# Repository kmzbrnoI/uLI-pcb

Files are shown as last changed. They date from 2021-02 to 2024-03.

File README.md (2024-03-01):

uLI – Ultimate LI PCB
=====================

uLI is a XpressNET &#8596; USB converter behaving as COM port in PC (CDC).

## uLI v5

* Designed in: KiCad 7
* Main Processor: PIC18F14K50
* Several enhancements from uLI v4, backward-compatible.
  - See releases/tags for a list of modifications from uLI v4.
* Firmware is same for v4 & v5.
* Authors: Jan Horacek (c) 2024

## uLI v4

* Deprecated.
* Designed in: Eagle 9
* Main Processor: PIC18F14K50
* Authors: Jan Horacek, Michal Petrilak (c) 2016

## Firmware

* [uLI-fw](https://github.com/kmzbrnoI/uLI-fw)
* [uLI-master-fw](https://github.com/kmzbrnoI/uLI-master-fw)

## Further reading

- [About XpressNET](http://www.opendcc.de/info/xpressnet/xpressnet_e.html)
- uLI meets [XpressNET specification v3](http://www.lenzusa.com/1newsite1/Manuals/xpressnet.pdf)
- uLI should also meet [XpressNET specification v3.6](http://wiki.rocrail.net/lib/exe/fetch.php?id=xpressnet-en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) (available only in German)

## License

Content of the repository is provided under [Creative Commons
Attribution-ShareAlike 4.0
License](https://creativecommons.org/licenses/by-sa/4.0/) as openhardware
project. You may download any data, contribute to the project, create PCB
yourself or even sell it yourself.

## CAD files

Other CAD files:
cnc/uLI-04-top.dwg
cnc/uLI-04-bottom.dwg

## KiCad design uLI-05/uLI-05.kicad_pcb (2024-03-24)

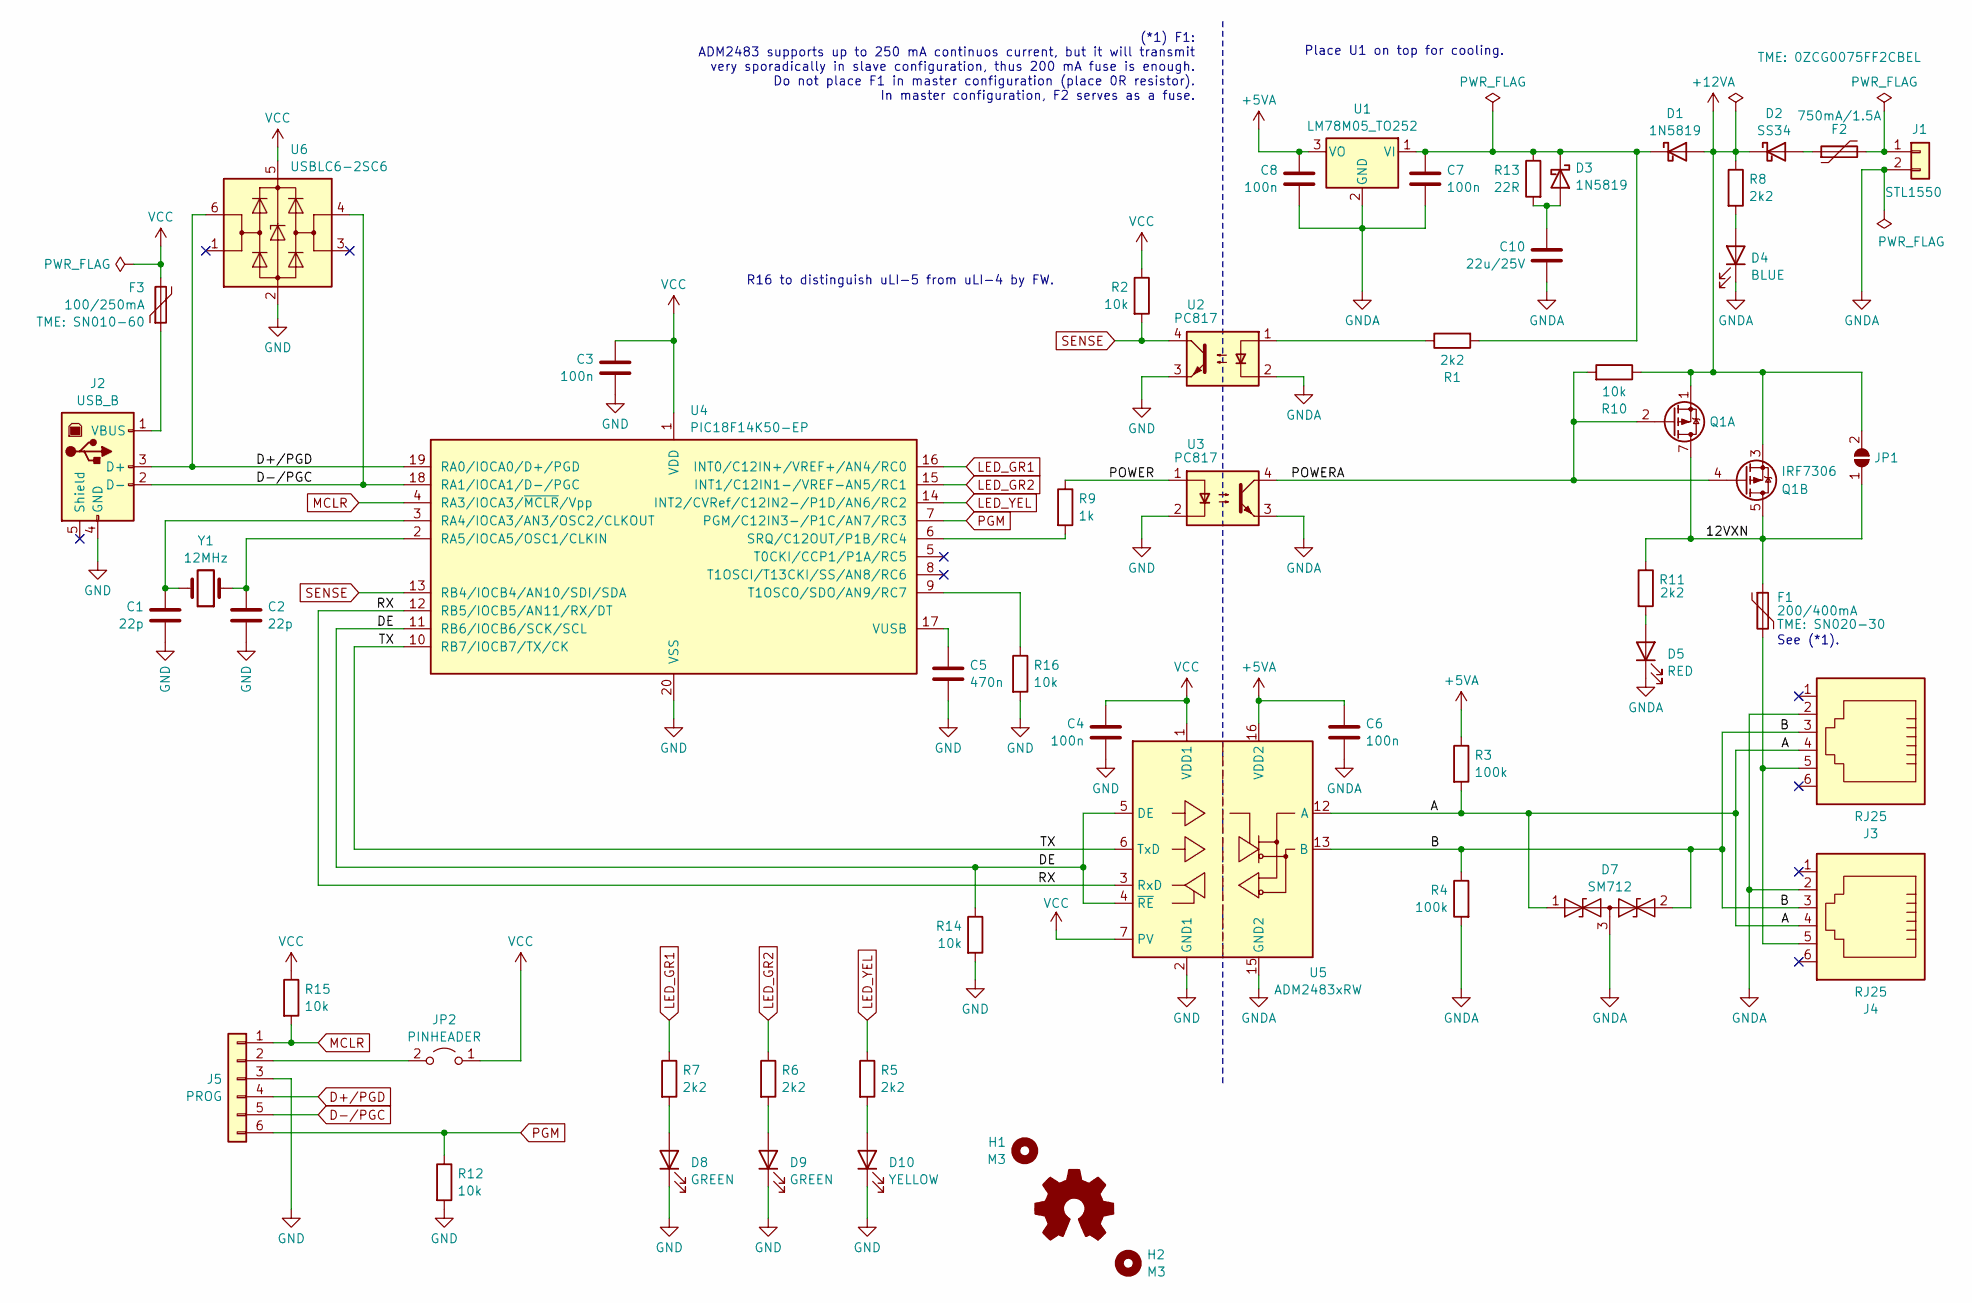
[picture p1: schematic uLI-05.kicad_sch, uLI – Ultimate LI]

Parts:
C1, C2: 22p; C_0805_2012Metric; LCSC C1804
C3, C4, C6, C7, C8: 100n; C_0805_2012Metric; LCSC C49678
C5: 470n; C_0805_2012Metric; LCSC C13967
C10: 22u/25V; C_0805_2012Metric; LCSC C45783
D1, D3: 1N5819; D_SOD-123; LCSC C8598
D2: SS34; D_SMA; LCSC C8678
D4: BLUE; LED_D3.0mm; JLCPCB_IGNORE true
D5: RED; LED_D3.0mm; JLCPCB_IGNORE true
D7: SM712; SOT-23; LCSC C32677
D8, D9: GREEN; LED_D3.0mm; JLCPCB_IGNORE true
D10: YELLOW; LED_D3.0mm; JLCPCB_IGNORE true
F1: 200/400mA; Fuse_1206_3216Metric; JLCPCB_IGNORE true
F2: 750mA/1.5A; Fuse_1812_4532Metric; JLCPCB_IGNORE true
F3: 100/250mA; Fuse_1206_3216Metric; JLCPCB_IGNORE true
H1, H2: M3; MountingHole_3.2mm_M3_Pad; JLCPCB_IGNORE true
J1: STL1550; PhoenixContact_MC_1,5_2-G-3.5_1x02_P3.50mm_Horizontal; JLCPCB_IGNORE true
J2: USB_B; USB_B_OST_USB-B1HSxx_Horizontal; JLCPCB_IGNORE true
J3, J4: RJ25; RJ12_Amphenol_54601-x06_Horizontal; JLCPCB_IGNORE true
J5: PROG; PinHeader_1x06_P2.54mm_Vertical; JLCPCB_IGNORE true
JP1: SolderJumper-2_P1.3mm_Open_RoundedPad1.0x1.5mm; JLCPCB_IGNORE true
JP2: PINHEADER; PinHeader_1x02_P2.54mm_Vertical; JLCPCB_IGNORE true
Q1: IRF7306; SOIC-8_3.9x4.9mm_P1.27mm; LCSC C879047
R1, R5, R6, R7, R8, R11: 2k2; R_0805_2012Metric; LCSC C17520
R2, R10, R12, R14, R15, R16: 10k; R_0805_2012Metric; LCSC C17414
R3, R4: 100k; R_0805_2012Metric; LCSC C149504
R9: 1k; R_0805_2012Metric; LCSC C17513
R13: 22R; R_0805_2012Metric; LCSC C17561
U1: LM78M05_TO252; TO-252-2; JLCPCB_IGNORE true
U2, U3: PC817; DIP-4_W7.62mm; JLCPCB_IGNORE true
U4: PIC18F14K50-EP; SSOP-20_5.3x7.2mm_P0.65mm; LCSC C12460
U5: ADM2483xRW; SOIC-16W_7.5x10.3mm_P1.27mm; LCSC C386280
U6: USBLC6-2SC6; SOT-23-6; JLCPCB_IGNORE true
Y1: 12MHz; Crystal_HC49-4H_Vertical; JLCPCB_IGNORE true

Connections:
+5VA: C6.1, C8.1, R3.1, U1.3 (VO), U5.16 (VDD2)
+12VA: D1.2 (A), D2.1 (K), JP1.2 (B), Q1.1 (S1), Q1.3 (S2), R8.1, R10.1
/12VXN: F1.1, JP1.1 (A), Q1.5 (D2), Q1.6 (D2), Q1.7 (D1), Q1.8 (D1), R11.1
/A: D7.1 (A1), J3.4, J4.4, R3.2, U5.12 (A)
/B: D7.2 (A2), J3.3, J4.3, R4.1, U5.13 (B)
/DE: R14.1, U4.11 (RB6/IOCB6/SCK/SCL), U5.4 (~RE), U5.5 (DE)
/POWER: R9.1, U3.1
/POWERA: Q1.2 (G1), Q1.4 (G2), R10.2, U3.4
/RX: U4.12 (RB5/IOCB5/AN11/RX/DT), U5.3 (RxD)
/TX: U4.10 (RB7/IOCB7/TX/CK), U5.6 (TxD)
D+/PGD: J2.3 (D+), J5.4, U4.19 (RA0/IOCA0/D+/PGD), U6.6 (I/O1)
D-/PGC: J2.2 (D-), J5.5, U4.18 (RA1/IOCA1/D-/PGC), U6.4 (I/O2)
GND: C1.1, C2.1, C3.2, C4.2, C5.2, D8.1 (K), D9.1 (K), D10.1 (K), J2.4 (GND), J5.3, R12.2, R14.2, R16.2, U2.3, U3.2, U4.20 (VSS), U5.2 (GND1), U5.8 (GND1), U6.2 (GND)
GNDA: C6.2, C7.2, C8.2, C10.2, D4.1 (K), D5.1 (K), D7.3 (common), J1.2, J3.2, J4.2, R4.2, U1.2 (GND), U2.2, U3.3, U5.9 (GND2), U5.15 (GND2)
LED_GR1: R7.1, U4.16 (INT0/C12IN+/VREF+/AN4/RC0)
LED_GR2: R6.1, U4.15 (INT1/C12IN1-/VREF-AN5/RC1)
LED_YEL: R5.1, U4.14 (INT2/CVRef/C12IN2-/P1D/AN6/RC2)
MCLR: J5.1, R15.2, U4.4 (RA3/IOCA3/~MCLR/Vpp)
unnamed: C7.1, D1.1 (K), D3.1 (K), R1.2, R13.1, U1.1 (VI)
unnamed: D2.2 (A), F2.1
unnamed: C10.1, D3.2 (A), R13.2
unnamed: D4.2 (A), R8.2
unnamed: D5.2 (A), R11.2
unnamed: D8.2 (A), R7.2
unnamed: D9.2 (A), R6.2
unnamed: D10.2 (A), R5.2
unnamed: F1.2, J3.5, J4.5
unnamed: F2.2, J1.1
unnamed: F3.1, J2.1 (VBUS)
unnamed: J5.2, JP2.2 (B)
unnamed: R1.1, U2.1
unnamed: C1.2, U4.3 (RA4/IOCA3/AN3/OSC2/CLKOUT), Y1.2
unnamed: C2.2, U4.2 (RA5/IOCA5/OSC1/CLKIN), Y1.1
unnamed: R9.2, U4.6 (SRQ/C12OUT/P1B/RC4)
unnamed: R16.1, U4.9 (T1OSCO/SDO/AN9/RC7)
unnamed: C5.1, U4.17 (VUSB)
PGM: J5.6, R12.1, U4.7 (PGM/C12IN3-/P1C/AN7/RC3)
SENSE: R2.2, U2.4, U4.13 (RB4/IOCB4/AN10/SDI/SDA)
VCC: C3.1, C4.1, F3.2, JP2.1 (A), R2.1, R15.1, U4.1 (VDD), U5.1 (VDD1), U5.7 (PV), U6.5 (VBUS)

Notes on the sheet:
R16 to distinguish uLI-5 from uLI-4 by FW.
Place U1 on top for cooling.
See (*1).
(*1) F1: ADM2483 supports up to 250 mA continuos current, but it will transmit very sporadically in slave configuration, thus 200 mA fuse is enough. Do not place F1 in master configuration (place 0R resistor). In master configuration, F2 serves as a fuse.

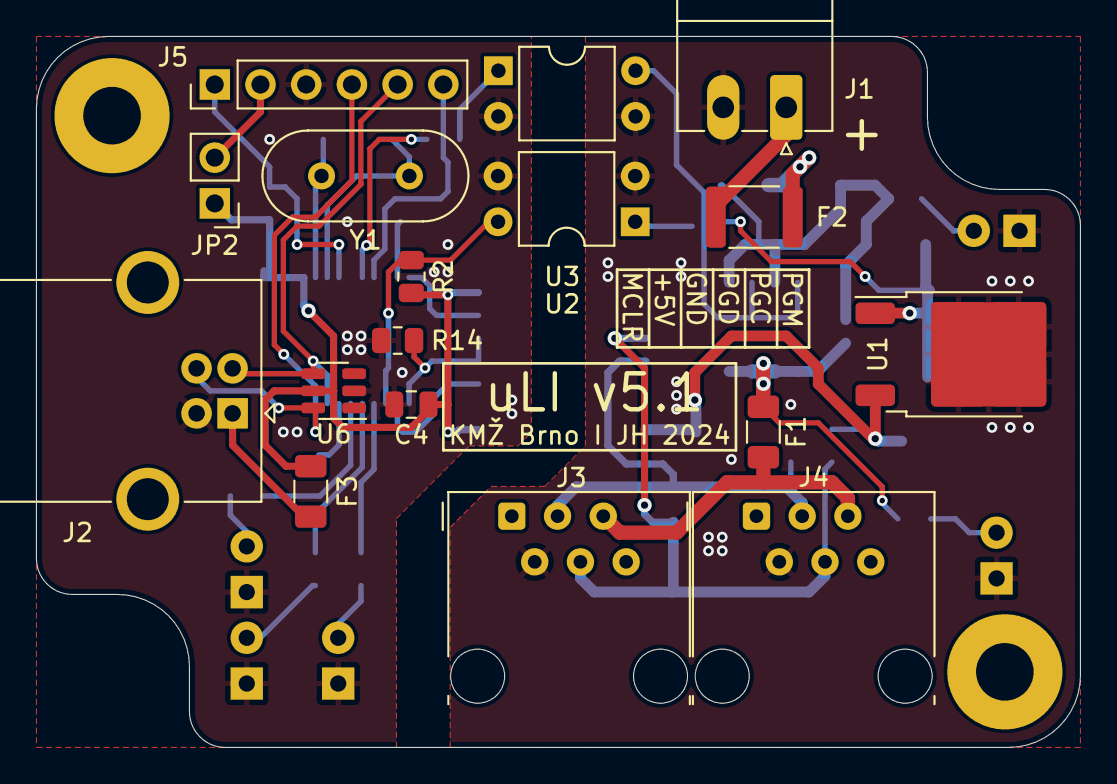
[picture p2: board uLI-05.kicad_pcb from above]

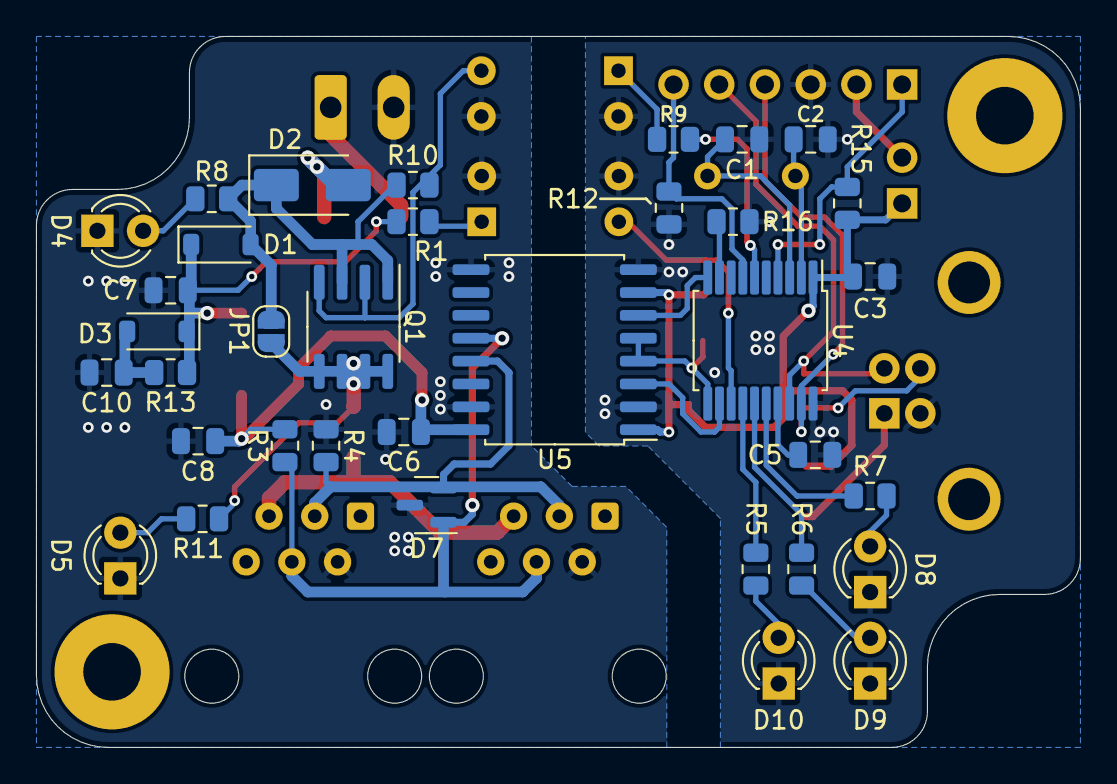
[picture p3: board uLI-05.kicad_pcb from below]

Board: 2 copper layers, 58.0 x 39.5 mm, 54 parts (35 on the bottom side), 39 nets.

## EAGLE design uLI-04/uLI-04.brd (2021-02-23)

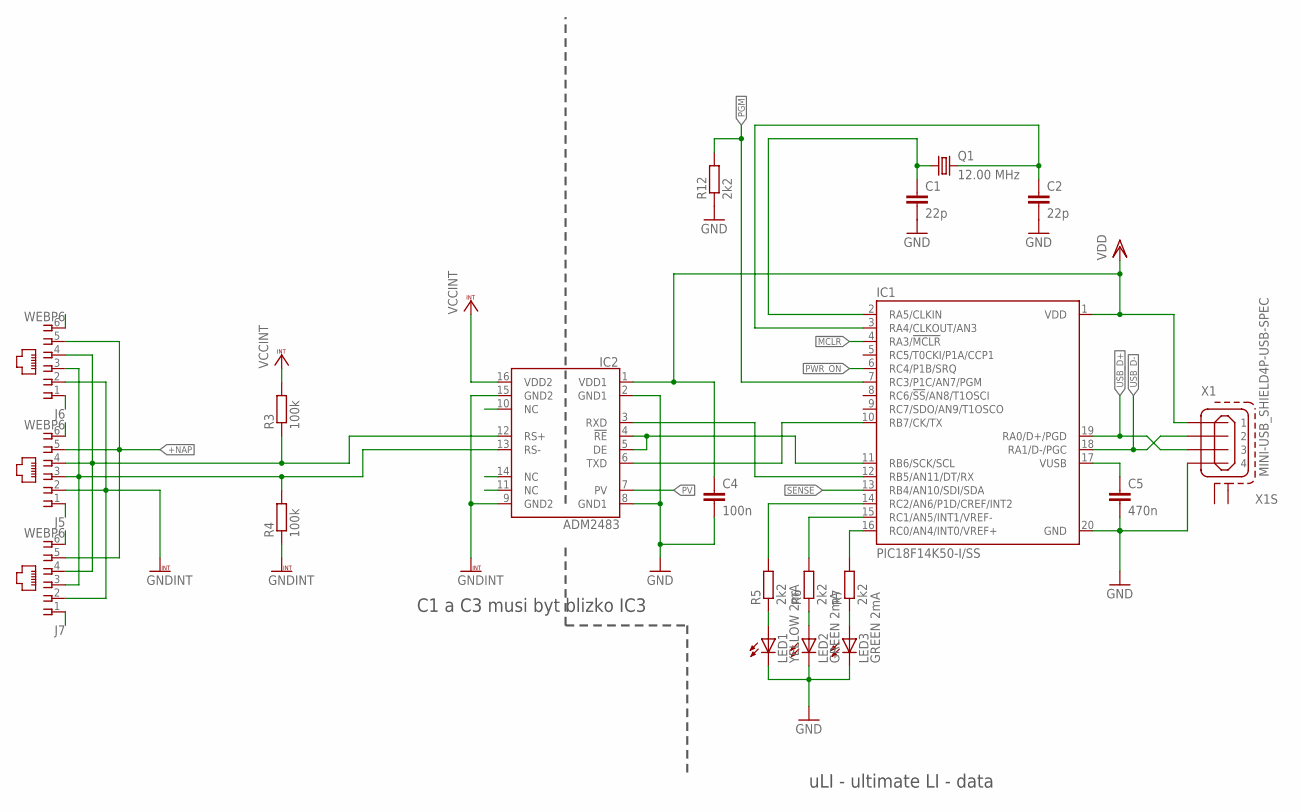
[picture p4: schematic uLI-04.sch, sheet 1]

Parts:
C1, C2: 22p; C0805
C4: 100n; C1206
C5: 470n; C1206
IC1: PIC18F14K50-I/SS; SSOP20
IC2: ADM2483; SO-16W
J5, J6, J7: WEBP6; WEBP6-6_SPEC2
LED1: YELLOW 2mA; LED3MM
LED2, LED3: GREEN 2mA; LED3MM
Q1: 12.00 MHz; HC49U70
R3, R4: 100k; R1206
R5, R6, R7, R12: 2k2; R1206
X1: MINI-USB_SHIELD4P-USB-SPEC; 85-32004-10X-SPEC

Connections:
!MCLR: IC1.4 (RA3/!MCLR!); also elsewhere on the board
+NAP: J5.5, J6.5, J7.5; also elsewhere on the board
BUS_A: IC2.12 (RS+), J5.4, J6.4, J7.4, R3.1
BUS_B: IC2.13 (RS-), J5.3, J6.3, J7.3, R4.2
GND: C1.2, C2.2, C4.2, C5.2, IC1.20 (GND), IC2.2 (GND1), IC2.8 (GND1), LED1.K (C), LED2.K (C), LED3.K (C), R12.1, X1.4; also elsewhere on the board
GNDINT: IC2.9 (GND2), IC2.15 (GND2), J5.2, J6.2, J7.2, R4.1; also elsewhere on the board
LED1: IC1.14 (RC2/AN6/P1D/CREF/INT2), R5.2
LED1_R: LED1.A, R5.1
LED2: IC1.15 (RC1/AN5/INT1/VREF-), R6.2
LED2_R: LED2.A, R6.1
LED3: IC1.16 (RC0/AN4/INT0/VREF+), R7.2
LED3_R: LED3.A, R7.1
unnamed: IC1.12 (RB5/AN11/DT/RX), IC2.3 (RXD)
NC2: IC2.14 (NC)
PGM: IC1.7 (RC3/P1C/AN7/PGM), R12.2; also elsewhere on the board
PROC_RX: IC1.10 (RB7/CK/TX), IC2.6 (TXD)
PROC_TE: IC1.11 (RB6/SCK/SCL), IC2.4 (!RE), IC2.5 (DE)
PV: IC2.7 (PV); also elsewhere on the board
PWR_ON: IC1.6 (RC4/P1B/SRQ); also elsewhere on the board
SENSE: IC1.13 (RB4/AN10/SDI/SDA); also elsewhere on the board
USB_D+: IC1.19 (RA0/D+/PGD), X1.3; also elsewhere on the board
USB_D-: IC1.18 (RA1/D-/PGC), X1.2; also elsewhere on the board
VBUS: C5.1, IC1.17 (VUSB)
VCCINT: IC2.16 (VDD2), R3.2; also elsewhere on the board
VDD: C4.1, IC1.1 (VDD), IC2.1 (VDD1), X1.1; also elsewhere on the board
XTAL1: C1.1, IC1.2 (RA5/CLKIN), Q1.1
XTAL2: C2.1, IC1.3 (RA4/CLKOUT/AN3), Q1.2

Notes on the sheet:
uLI - ultimate LI - data
C1 a C3 musi byt blizko IC3

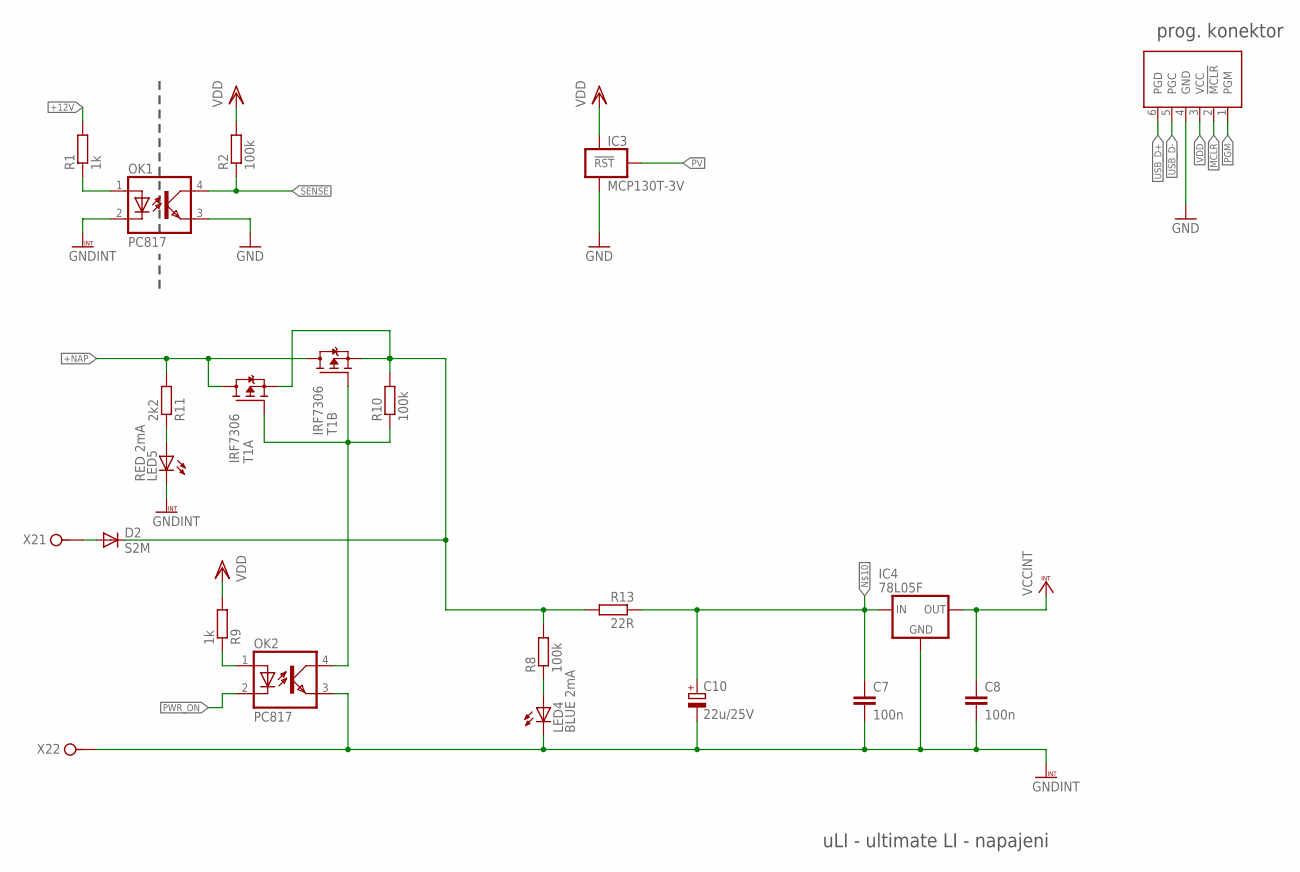
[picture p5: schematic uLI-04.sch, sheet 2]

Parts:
C7, C8: 100n; C1206
C10: 22u/25V; E2-5
D2: S2M; SMB
IC3: MCP130T-3V; SOT23
IC4: 78L05F; SOT89
J1: PICPROG2-V; 6410-06-PICPROG
LED4: BLUE 2mA; LED3MM
LED5: RED 2mA; LED3MM
OK1, OK2: PC817; DIL04
R1, R9: 1k; R1206
R2, R8, R10: 100k; R1206
R11: 2k2; R1206
R13: 22R; R1206
T1: IRF7306; SO08-IRF
X2: ARK1550/2_S; ARK1550/2_SPEC

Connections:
!MCLR: J1.2 (!MCLR); also elsewhere on the board
+12V: D2.C, R1.2, R8.2, R10.2, R13.2, T1.1 (S), T1.3 (S)
+NAP: R11.2, T1.5 (D), T1.6 (D), T1.7 (D), T1.8 (D); also elsewhere on the board
+NAP2: D2.A, X2.1
BUS_SENSE: OK1.1 (A), R1.1
GND: IC3.3 (GND), J1.4 (GND), OK1.3 (EMIT); also elsewhere on the board
GNDINT: C7.2, C8.2, C10.-, IC4.2 (GND), IC4.2@1 (GND), LED4.K (C), LED5.K (C), OK1.2 (C), OK2.3 (EMIT), X2.2; also elsewhere on the board
unnamed: LED4.A, R8.1
unnamed: LED5.A, R11.1
unnamed: OK2.4 (COL), R10.1, T1.2 (G), T1.4 (G)
unnamed: OK2.1 (A), R9.1
unnamed: C7.1, C10.+, IC4.3 (VI), R13.1
PGM: J1.1 (PGM); also elsewhere on the board
PV: IC3.1 (!RST); also elsewhere on the board
PWR_ON: OK2.2 (C); also elsewhere on the board
SENSE: OK1.4 (COL), R2.1; also elsewhere on the board
USB_D+: J1.6 (PGD); also elsewhere on the board
USB_D-: J1.5 (PGC); also elsewhere on the board
VCCINT: C8.1, IC4.1 (VO); also elsewhere on the board
VDD: IC3.2 (VCC), J1.3 (VCC), R2.2, R9.2; also elsewhere on the board

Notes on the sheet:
uLI - ultimate LI - napajeni
prog. konektor

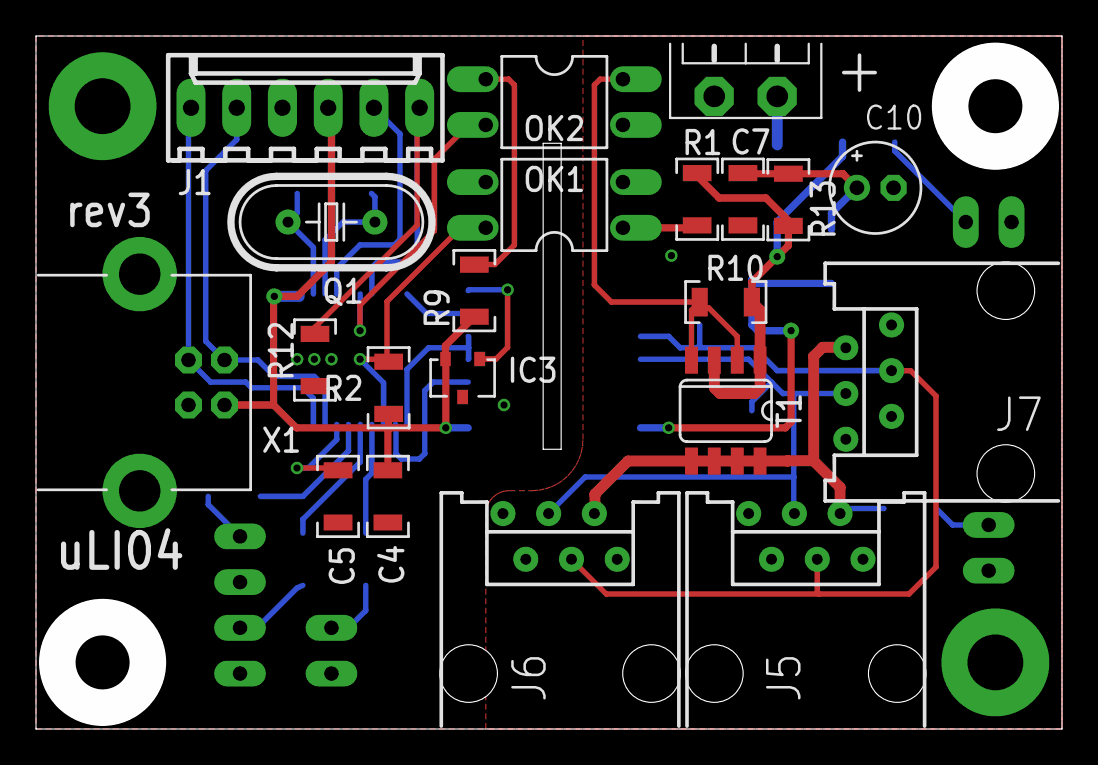
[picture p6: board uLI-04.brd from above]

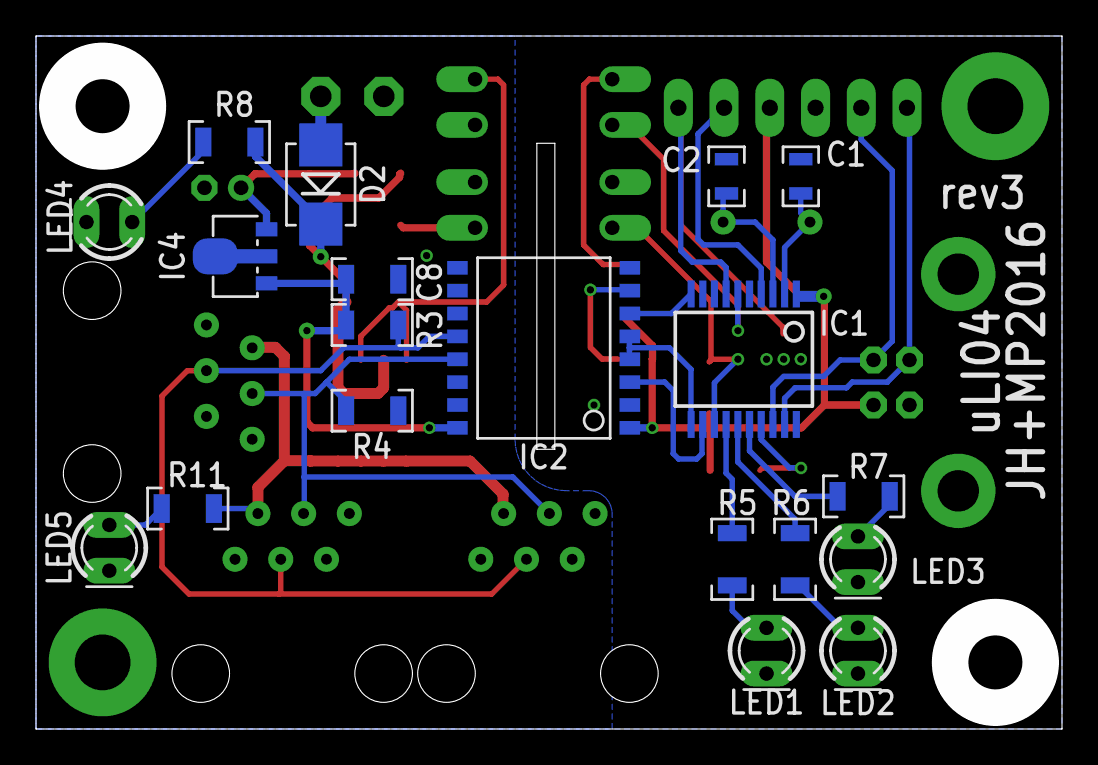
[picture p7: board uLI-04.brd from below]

Board: 2 copper layers, 57.0 x 38.5 mm, 40 parts (19 on the bottom side), 34 nets.

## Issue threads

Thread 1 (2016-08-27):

DRC

horacekj, 2016-08-27:
defaultně nastavené DRC - třeba izolační mezera 6mil, mi nepříjde moc dobrá, já používám 0.3mm. Resp. na generování rozlivů používám přísnější pravidla než pak na kontrolu desky, abych měl 100% jistotu, že se výroba povede.

horacekj, 2016-08-27:
@petrilakm Na electrow píší: Minimum Track/Vias Space: 6mil (Recommend >8mil).
Co navrhuješ změnit?

petrilakm, 2016-08-27:
Ahoj,

má používám nastavení na 0.3mm

mám vždy 2 DRC soubory. Jedním s kterým desku kreslím (0.3 mm), pak dám
"ratenest" (vygeneruje se rozliv mědi) a přepnu na druhý DRC soubor (kde
jsou limity výroby). A už kliknu jen na DRC check.
Když něco změním, tak musím přepnou na původní (můj) DRC definiční
soubor a dám "ratenest".

Takže rozliv mám vygenerován na 0.3mm ale kontroluje zda celá deska
splňuje 6mil.
Mě totiž příjde jako blbost dělat rozliv úplně na okraji technologického
limitu výroby. Ale zase je potřeba pouštět DRC kontrolu podle požadavků
výroby. Protože když pustím DRC kontrolu s tím svím upraveným DRC, tak
prakticky nikdy neprojde patice SSOP).

Já rozlišuji 2 normy:
1) jak chci aby deska vypadala
2) co zvládne výrobní firma vyrobit

proto mám ty 2 DRC soubory.

Svoje vlasní limity si definuji sám, dle kvalifikovaného odhadu (kdybych
třeba dal izolaci 0.5mm, tak se rozliv neprolije kolem spousty míst a
měl bych problémy)

M.P.

Dne 27.8.2016 v 17:32 Jan Horacek napsal(a):
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

---
Tato zpráva byla zkontrolována na viry programem Avast Antivirus.
https://www.avast.com/antivirus

horacekj, 2016-08-28:
To zní smysluplně. Je Tvé DRC někde k dispozici? Pošleš mi ho prosím? Díky.

horacekj, 2016-08-29:
DRC upraveno.

Closed 2016-08-29.

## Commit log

2016-05-23 Initial commit.
    [uLI-00.brd, uLI-00.sch, uLI-02.brd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]
2016-06-12 Napajeci spoje ztlusteny na 0.4 mm.
    [uLI-04.brd]
2016-06-12 Pouzito DRU seedstudio.
    [uLI-04.brd]
2016-06-12 Odstranen prebytecny kondenzator 100 n.
    [uLI-04.brd, uLI-04.sch]
2016-06-12 Presunuty popisky soucastek.
    [uLI-04.brd]
2016-06-12 Obrys krabicky presunut do vrstvy "krab".
    [uLI-04.brd]
2016-06-12 DRU -> electrow.
    [uLI-04.brd]
2016-08-14 Upraven osazovak.
    [uLI-04.brd]
2016-08-15 uLI-04 rev 2.
    Opraveny chyby uLI-04 zjistene behem testovani:
    * upraven obrys krabicky podle realnych rozmeru (zvetseno symtetricky 1 mm do sirky a 0.5 mm do vysky)
    * posunuty otvory pro srouby do krabicky o 0.5 mm v kazde ose smerrem ke kraji
    * prohozeno RX a TX mezi procesorem a ADUMem
    * opraveno zdcadlove zapojeni XpressNETich konektoru
    [uLI-04.brd, uLI-04.sch]
2016-08-16 Odstranena ochrana dioda na vstupu z USB.
    [uLI-04.brd, uLI-04.sch]
2016-08-17 Omezeni proudovych razu - schema
    Pridan na schema rezistor a zmensen kondenzator pred stabilizator.
    Editovano jen schema. Deska neupravena.
    [uLI-04.brd, uLI-04.sch]
2016-08-17 Pridan brown-out reset pro PV pin
    Jen schema.
    [uLI-04.brd, uLI-04.sch]
2016-08-21 Doplnena data pro frezovani krabicky.
    [uLI-04-bottom.dwg, uLI-04-top.dwg]
2016-08-22 Dokreslen rezistor 22 Ohm.
    [uLI-04.brd]
2016-08-22 Dokreslen brown-down obvod do DPS.
    [uLI-04.brd]
2016-08-22 Upravena hodnota kondenzatoru XN na 22uF.
    [uLI-04.brd, uLI-04.sch]
2016-08-22 Variantni zapojeni nabijeciho rezistoru.
    [uLI-04.sch]
2016-08-27 6-4 > 6-6, ploska J5.
    * Konektory WEBP 6-4 nahrazeny za WEBP 6-6. Close #3.
    * Pajeci ploska pobliz J5 odstranena. Close 2.
    [uLI-04.brd, uLI-04.sch]
2016-08-27 Progrmaovaci konektor posunut o 0.5 mm doleva.
    Close #7.
    [uLI-04.brd]
2016-08-27 Odstranen kus dratu u stabilizatoru.
    Close #6.
    [uLI-04.brd]
2016-08-27 Posunut C5.
    Close $5.
    [uLI-04.brd]
2016-08-27 Velikost vnejsiho okraje prokovu -> 0.9 mm.
    Close #4.
    [uLI-04.brd]
2016-08-29 Drobne zmeny.
    * Upraveno DRC na bezpecnejsi mezery.
    * Prokovy nastaveny globalne na 0.4 mm.
    * Posunuta dioda S2M.
    [uLI-04.brd]
2016-08-29 Upraveny pozice hodnot a nazvu soucastek.
    [uLI-04.brd]
2016-08-29 Doplnen nepropojeny vodic.
    [uLI-04.brd]
2016-09-27 Doplnen rezistor 10k na pin PGM (#9).
    [uLI-04.brd, uLI-04.sch]
2017-10-16 Add colors of LEDs.
    [uLI-04.brd, uLI-04.sch]
2017-10-16 Do not use optoislators in slave variant.
    [uLI-04.brd, uLI-04.sch]
2017-10-16 Do blue LED in slave variant.
    [uLI-04.brd, uLI-04.sch]
2017-10-27 Move texts in mounting scheme.
    [uLI-04.brd]
2018-08-01 Remove unused uLI boards.
    [uLI-00.brd, uLI-00.sch, uLI-02.brd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]
2019-03-15 Change value of LED resistors based on reality.
    [uLI-04.brd, uLI-04.sch]
2019-03-15 Set precise MCP's voltage.
    [uLI-04.brd, uLI-04.sch]
2021-02-23 Minor board tweaks.
    [uLI-04.brd]
2024-02-15 Add uLI-05 KiCad empty project.
    [uLI-05.kicad_pcb, uLI-05.kicad_sch]
2024-02-15 Copy schematics from uLI-04.
    Changes compared to uLI-04:
    * Add SM712 protection to Ale asiXpressNET
    * Add ESDA6V1 protection to USB
    * Change prog connector pnout to match PICKit
    * Unify pull-ups to 10k
    * Connect ADM2483's PV directly to VCC
    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
    [uLI-05.kicad_sch]
2024-02-15 Add another diode to power supply.
    So XpressNET devices do not drain our internal capacitors.
    [uLI-05.kicad_sch]
2024-02-15 Add mounting holes, use 1N5819 as schottky diodes.
    [uLI-05.kicad_sch]
2024-02-15 Add option to bridge IRF7306 (slave variant).
    [uLI-05.kicad_sch]
2024-02-15 Add DE pull-down.
    [uLI-05.kicad_sch]
2024-02-17 Use part names from uLI-04.
    [uLI-05.kicad_sch]
2024-02-17 Add footprints.
    [uLI-05.kicad_sch]
2024-02-17 Use USBLC6 for USB protection.
    Benefits:
    * USBLC6 is specifically designed for USB
    * It also protects VCC
    [uLI-05.kicad_sch]
2024-02-17 Add R16 distinguish resistor.
    To distinguish between uLI-4 & uLI-5 in firmware.
    [uLI-05.kicad_sch]
2024-02-18 pcb: import mechanical from uLI-4, draw outline.
    [uLI-05.kicad_pcb]
2024-02-18 pcb: place connectors & LEDs.
    Place on same positions as in uLI-4.
    [uLI-05.kicad_pcb, uLI-05.kicad_sch]
2024-02-18 Add STL1550 power connector.
    [uLI-05.kicad_pcb, uLI-05.kicad_sch]
2024-02-18 pcb: wire USB part.
    [uLI-05.kicad_pcb, uLI-05.kicad_sch]
2024-02-19 pcb: wire XpressNET part.
    [uLI-05.kicad_pcb, uLI-05.kicad_sch]
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2024-02-20 Fix issues reported by DRC.
    [uLI-05.kicad_pcb]
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2024-02-24 Use SS34 as D2.
    SS34 supports larger maximum current.
    [uLI-05.kicad_pcb, uLI-05.kicad_sch]
2024-02-29 F1, F2, F3: add JLCPCB_IGNORE.
    [uLI-05.kicad_pcb, uLI-05.kicad_sch]
2024-02-29 Move uLI-04 data to 'uLI-04' directory.
    [uLI-04.brd, uLI-04.sch]
2024-02-29 D1, D2: add JLCPCB_CORRECTION.
    [uLI-05.kicad_pcb, uLI-05.kicad_sch]
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2024-03-23 Use 3.0 drills for RJ12 connectors.
    So the RJ12 connectors fit into the holes more precisely.
    [uLI-05.kicad_pcb, uLI-05.kicad_sch]
2024-03-24 Fix C6 position.
    Was outside of the board, move to appropriate place.
    [uLI-05.kicad_pcb]

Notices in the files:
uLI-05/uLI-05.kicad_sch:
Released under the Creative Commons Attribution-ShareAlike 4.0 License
